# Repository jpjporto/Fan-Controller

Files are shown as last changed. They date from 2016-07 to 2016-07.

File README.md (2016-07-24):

# Fan-Controller
Fan controller system for watercooled computer. The board currently monitors the inlet/outlet temperature of each radiator in the system, and then sets the desired fan speed based on the difference between the average loop temperature and the external temperature.
The board also monitors the flow rate in the system, and can set the pump to match a desired flow rate.
The board is also capable of driving a RGB LED strip along with a single color LED strp (UV LEDs in my case).

Lastly, the board has WiFi capabilities through an ESP8266 board. Currently the code is able to interfarce with MSI Afterburner Remote Server and read the CPU & GPU temperatures.
I haven't developed this part much (mostly due to lack of time), but my idea is to have the board send out information such as fan speeds and have the user read out the information on a webserver or an app. This would also allow the user to change the LED colors and brightness.

The board is powered via a single molex connector (AMP MATE-N-LOK 1-480424-0). Obviously, the power used depends on how many fans/which fans are used and the LEDs used. The 12V trace powering the fans/LEDs is 75mils wide, so it is not recommended pulling more than 6Amps through the 12V for a 1oz copper board.
For reference, a Corsar SP120 High-performance PWM fan draws around 0.13 Amps at 100% duty cycle (and 0.2 Amps during power up). A 5050 LED strip with 18 SMDs/ft draws around 0.2 Amps per feet.

### Capabilities ###
* Control and monitor up to 7 PWM fans (can control more if using 4-pin fan cable splitters)
* Control and monitor 1 Pump
* Monitor up to 7 10k Ohms temperature sensors (6 inline sensors and 1 external sensor)
* Monitor 1 flow sensor (the code is desined to use a Koolance INS-FM17N flow meter, but can be easily modified to support different sensors)
* Brightness and Color control of an RGB LED strip and a single color LED strip.
* WiFi (needs to be developed though)

### Configuration ###
Sadly, this project is (currently) not simply "plug-and-play". The user needs to modify a few things to get the code working. 
Most importantly, one needs to modify the first few lines of the esp_main.ino code to add their SSID and MSI afterburner information.
The user also needs to modify the wc_board.ino code so it knows how many fans are being connected and how many radiators/temp sensors the system has.

### To-Do List ###
* Control/monitor throught wifi
* Warn the user if the pump has stopped or if the temperature gets really high. Since I don't have a buzzer, one idea was to have the LEDs flash.
* Add some nice light effects, like fade-in, or rainbow cycle.
* Fan calibration (i.e. find slowest operating speed)
* Detect number of fans and sensors connected, and automatically calibrate the system.
* Fan RPM control. The MAX31790 chips support controlling the fans by setting the desired RPM rate (as opposed to setting the desired duty cycle). I tried this before but for some reason it wasn't working.
* Figure out how to have Windows recognize the board so monitoring softwares (like HWMonitor, Corsair Link, or MSI Afterburner) could report fan speeds and loop temperatures.
* Improve this readme file.

If anyone is interested in helping out with the code, feel free to push commits.

### Repository structure ###

* ./esp_main

Includes the code for the ESP8266 board. For more information about the ESP8266 board and flashing it, please refer to https://github.com/esp8266/Arduino

* ./libraries

Includes the necessary libraries to run the Teensy code. The I2Cdev library included is probably out-of-date, but guaranteed to work with the code in this repo.

* ./PCB

Includes all the schematic files necessary to modify the pcb board along with gerber files for manufacturing. The pcb was generated using Altium Designer 16, however, feel free to email me asking for files for difference programs. I believe Altium allows me to generate source files for many different programs.

* ./wc_board

Includes the main code. I'm using a Teensy 3.2.

### Third-Party Software ###
I've used the MSI Afterburner GUI & Remote Server application for my code. Both are available on the [MSI Afterburner website](http://event.msi.com/vga/afterburner/overview.htm). This code is currently capable of interfacing with MSI Afterburner versions :
* MSI Afterburner GUI Version 4.1.1.7625
* MSI Afterburner Remote Server v1.2.0.0

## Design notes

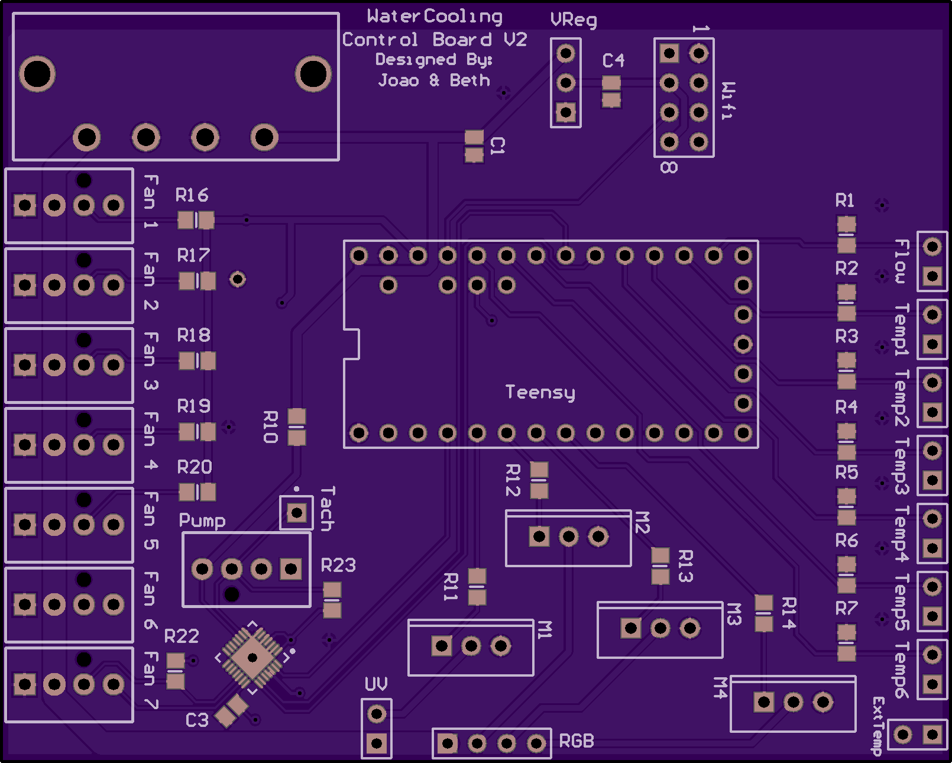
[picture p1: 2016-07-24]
PCB/pcb_top.png

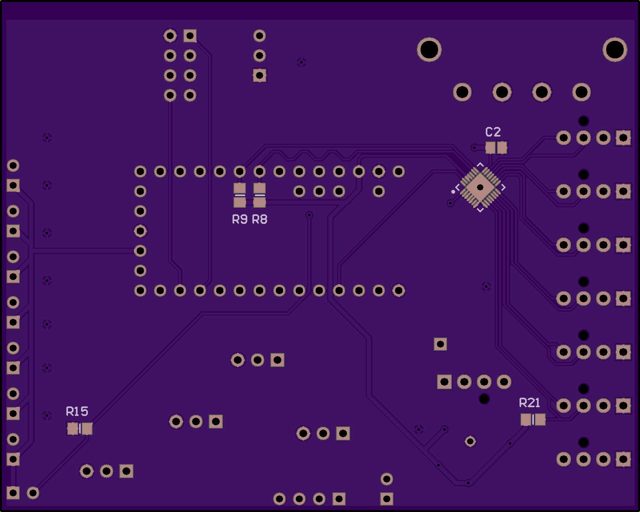
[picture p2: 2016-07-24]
PCB/pcb_bottom.png

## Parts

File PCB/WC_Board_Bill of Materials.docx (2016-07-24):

WaterCooling Board:

Description | Digikey P/N | Qnty | Board Reference
IC MOTOR CONTROLLER I2C 28TQFN MAX31790 | MAX31790ATI+-ND | 2
MOSFET N-CH 30V 62A TO-220AB | IRLB8721PBF-ND | 4 | M(1-4)
IC REG LDO 3.3V 0.8A TO220AB | 497-1491-5-ND | 1 | Vreg
RES SMD 10K OHM 1% 1/8W 0805 | 1276-5332-1-ND | 12 | R(1-7,10-14)
RES SMD 4.7K OHM 1% 1/8W 0805 | P4.70KCCT-ND | 2 | R8,R9
CAP 0.1uF 50V CERAMIC X7R 0805 | 399-1170-1-ND | 3 | C1,C2,C3
CAP 10uf 16V CERAMIC X5R 0805 | 399-8012-1-ND | 1 | C4
MOLEX POWER CONNECTOR | A122356-ND | 1
4PIN FAN HEADER | WM4330-ND | 8 | FAN (1-7), PUMP
TERM BLOCK 2POS SIDE ENT 2.54MM | A98333-ND | 1 | UV
TERM BLOCK 4POS SIDE ENT 2.54MM | A98335-ND | 1 | RGB
8 Position Header Connector 0.100" (2.54mm) Through Hole Tin | S7072-ND | 1 | Wifi
Headers
Teensy 3.2 | 1568-1231-ND | 1
ESP8266 | 1568-1235-ND | 1

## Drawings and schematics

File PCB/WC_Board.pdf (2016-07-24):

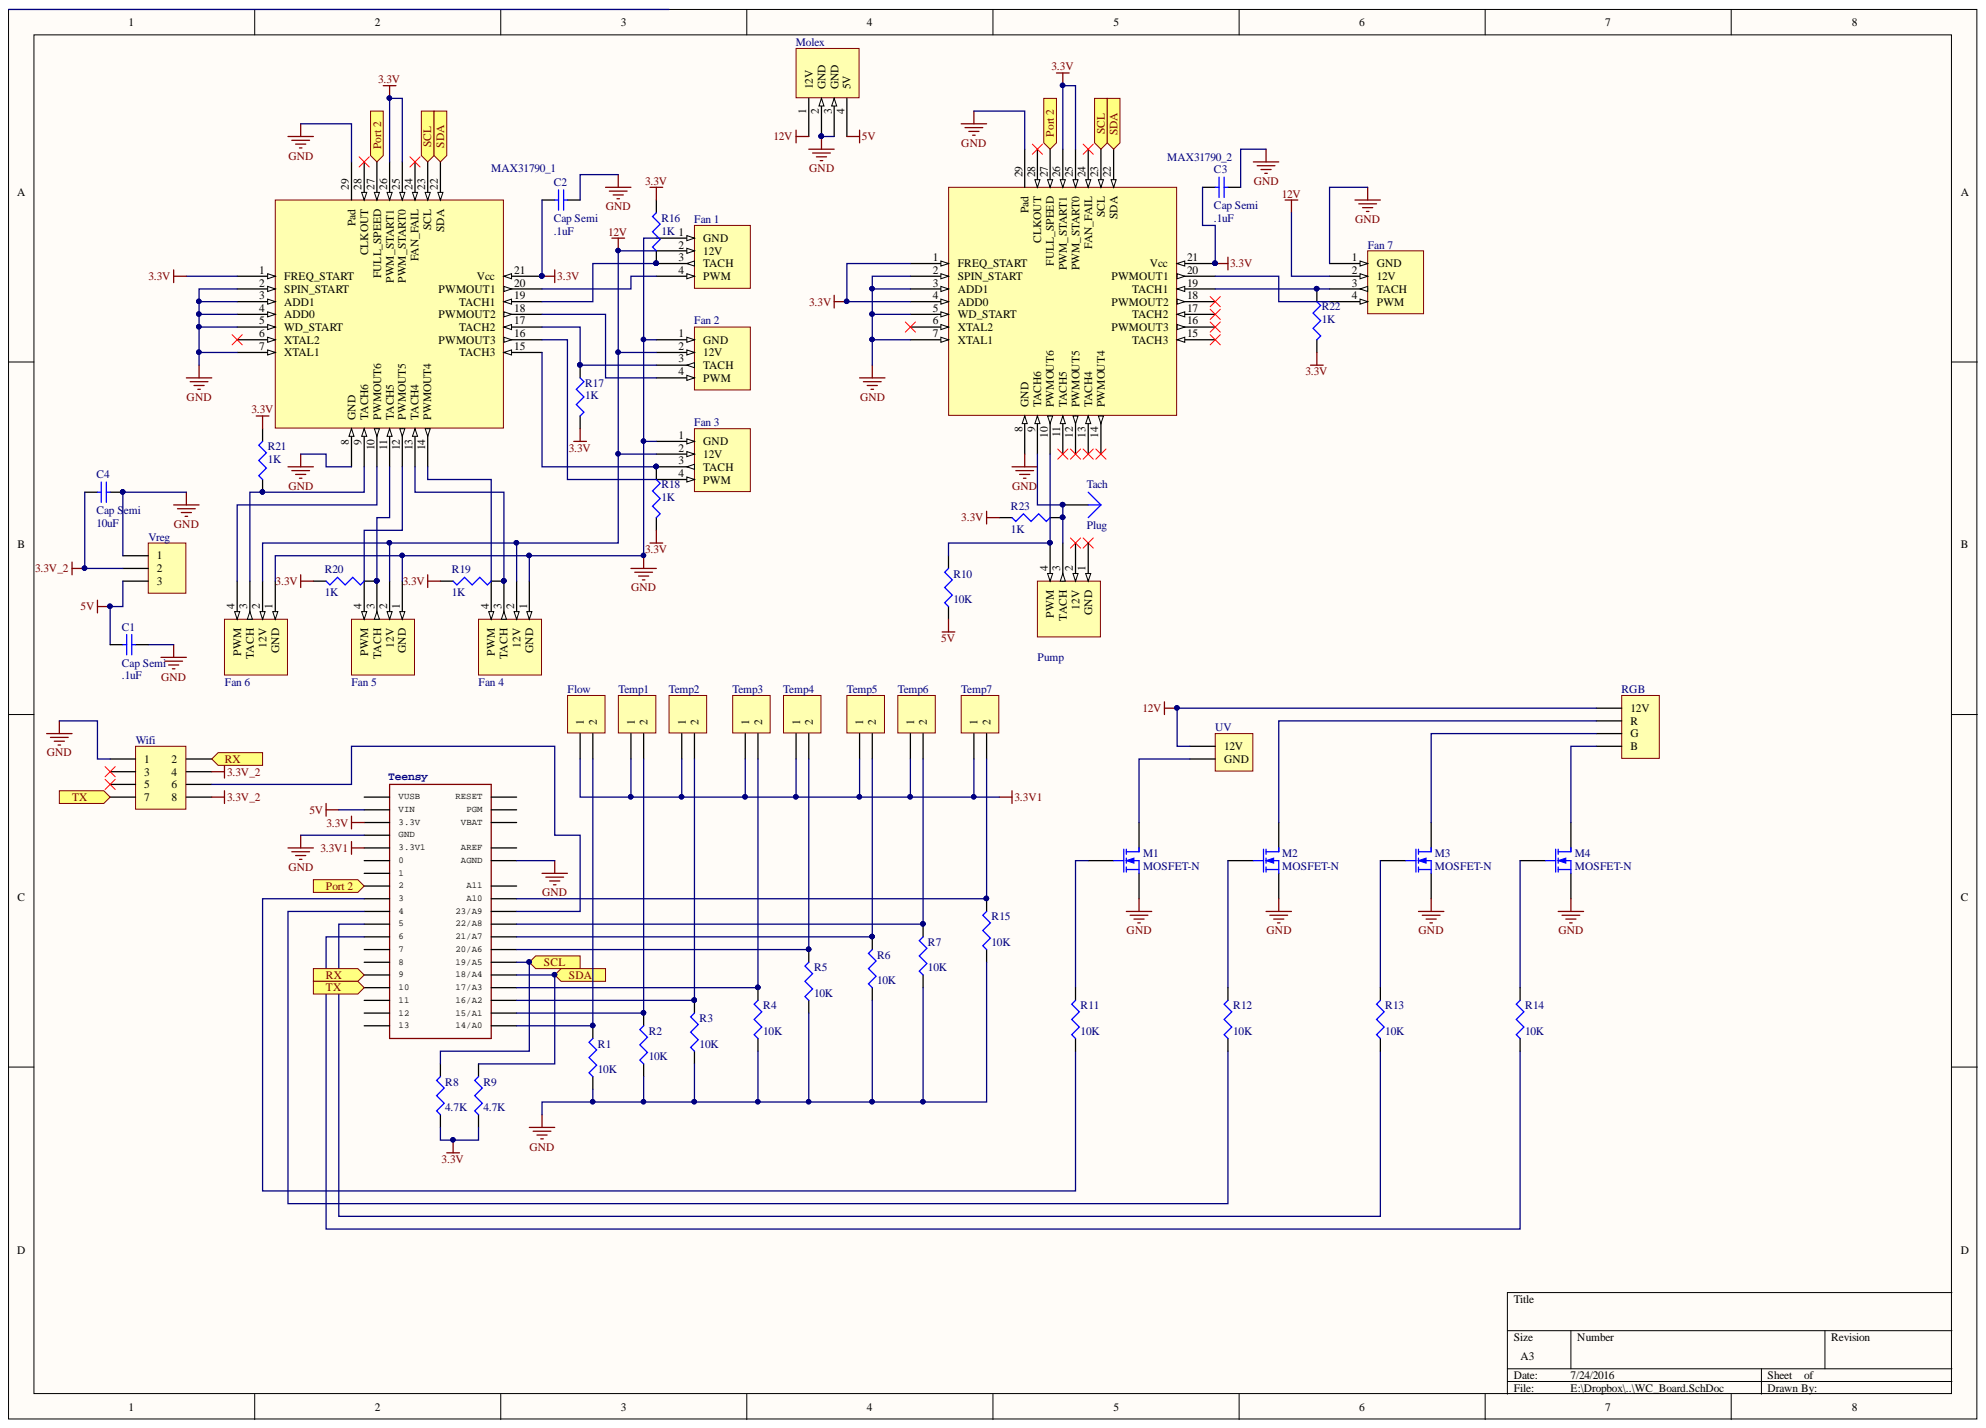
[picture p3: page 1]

SDA 22 SCL 23 FAN_FAIL 24 PWM_START0 25 PWM_START1 26 FULL_SPEED 27 CLKOUT 28 Pad 29

XTAL1 7 | 12V 2

TACH 3
PWM 4

Cap Semi 10uF | Vreg

GND 1 12V 2 TACH 3 PWM 4 Pump

GND 1 12V 2 TACH 3 PWM 4 Fan 6

GND 1 12V 2 TACH 3 PWM 4 Fan 5

GND 1 12V 2 TACH 3 PWM 4 Fan 4

4 23/A9
5 22/A8 | R15

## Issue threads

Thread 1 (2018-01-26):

Pull-Ups on PWM pins

dross92, 2018-01-26:
Hi,
I am designing a circuit using the MAX31790 and have referenced your design.  I noticed that you wire the fan's PWM pin straight into the MAX's PWMOUT, however the MAX datasheet specifies PWMOUT is an open-drain output so it must be pulled up to Vcc.  Basically, I was wondering if your circuit functioned properly without these pull-ups.
Please let me know.

Thanks,
Drew

jpjporto, 2018-01-26:
Hi,

The circuit assumes that the fan connected follows the [4-Wire PWM Fan Specs](http://www.formfactors.org/developer%5Cspecs%5C4_Wire_PWM_Spec.pdf), so each fan internally pulls the PWM signal to Vcc.

Best,
Joao

dross92, 2018-01-26:
OK, thank you!

Closed 2018-01-26.

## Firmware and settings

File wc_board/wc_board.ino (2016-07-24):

/*************************************************
 *	
 *	Watercooling Board Control Software
 *	For use with watercooling board available at https://github.com/jpjporto/Fan-Controller
 *
 *	Latest update on 07/24/2016 by Joao Paulo Porto <jpjporto(at)gmail.com>
 *
 *	Important Notice: This code has been stably running on my loop for at least a month (up to 14hours).
 *		However, I make no guarantees about it.
 *
 *	If you think this code is cool, feel free to use or modify it. However, it would be nice of you to
 *	let me know and give proper attribution back.
 *
 *	Changelog:
 *		v0.1.0 - First release.
 *
 *************************************************/


#include <i2c_t3.h>
#include "MAX31790.h"
#include "I2Cdev.h"
#include <PID_v1.h>

//Pin definitions
#define TEMP1 A1
#define TEMP2 A2
#define TEMP3 A3
#define TEMP4 A6
#define TEMP5 A7
#define TEMP6 A8
#define TEMP_EXT A10 //external temp
#define FLOW  14
#define FULL_SPEED  2
#define UV_PIN 3
#define G_PIN 4
#define R_PIN 5
#define B_PIN 6
#define ESP_RST 23

//System defs
#define NUM_RADS 2
#define NUM_FANS 5
#define NUM_TEMP 5 //rads*2 + 1

//MAX31790 fan_board(B0100000);
MAX31790 fan_board(0x40 >> 1);
MAX31790 fan_board2(0x46 >> 1);

char incomingByte = 0;

const int ANALOG_READ_RESOLUTION = 10; // Bits of resolution for the ADC.
const int ANALOG_READ_AVERAGING = 4;  // Number of samples to average with each ADC reading.

//Temp sensor values
uint16_t _nominalResistance = 10000;
uint16_t _seriesResistance = 10000;
uint16_t _betaCoefficient = 3950;
uint8_t _nominalTemperature = 25;

elapsedMillis flow_dt, flow_sample, temp_sample, fan_sample;
unsigned long timenow, lastPump, lastTemp;

uint32_t flow_read = 0;
uint8_t flow_count = 0;
double FlowMeas, prevFlowMeas, favg;
double FlowFreq;

double Setpoint = 1; //Desired flow = 1 gpm
double Output = 480; //Pump starting rate;

PID pumpPID(&FlowMeas, &Output, &Setpoint, 2, 6, 0.5, DIRECT);

//Sample Times
uint32_t Ts_pump = 500; // Flow sensor sample time, 0.5 seconds
uint32_t Ts_temp = 10;  // Get new temp data every 10msec
uint32_t Ts_fan  = 1000; // Check temperature readings and update fan speeds every 1 second

float rad_input[NUM_RADS], rad_output[NUM_RADS], ext_temp, rad_avg;
uint16_t fanspeed[NUM_FANS];
uint16_t pumpspeed;

bool temp_flag = 0;
uint8_t tempCount = 0;
uint32_t tempSum[NUM_TEMP];
float tempAvg[NUM_TEMP];

int MSI_cpu_temp, MSI_gpu_temp;
bool MSI_data = false;

// Fan curve settings
// please modify this to desired numbers.
uint8_t fan_dT[]  = {5,  10, 15, 20, 25, 30};
uint8_t fan_PWM[] = {40, 60, 70, 80, 90, 100};
float dT;
uint8_t steps = 6;
uint16_t fanPWMTarget;

//Struct for rgb strings
struct COLOR {
  uint8_t r;
  uint8_t g;
  uint8_t b;
};

COLOR default_color = {0, 0, 50};

void setup() {
  Wire.begin();
  Serial.begin(115200);
  Serial2.begin(115200);
  Serial2.setTimeout(100);

  pinMode(FLOW, INPUT);
  pinMode(TEMP1, INPUT);
  pinMode(TEMP2, INPUT);
  pinMode(TEMP3, INPUT);
  pinMode(TEMP4, INPUT);
  pinMode(TEMP5, INPUT);
  pinMode(TEMP6, INPUT);
  pinMode(TEMP_EXT, INPUT);

  pinMode(UV_PIN, OUTPUT);
  pinMode(R_PIN, OUTPUT);
  pinMode(G_PIN, OUTPUT);
  pinMode(B_PIN, OUTPUT);
  pinMode(FULL_SPEED, OUTPUT);
  //pinMode(ESP_RST, OUTPUT);

  analogReadResolution(ANALOG_READ_RESOLUTION);
  analogReadAveraging(ANALOG_READ_AVERAGING);

  digitalWrite(FULL_SPEED, HIGH);
  //digitalWrite(ESP_RST, LOW);

  setUV(200);
  setRGB(default_color);


  fan_board.initialize();
  fan_board2.initialize();

  pumpPID.SetOutputLimits(0, 511);
  pumpPID.SetSampleTime(Ts_pump);
  //pumpPID.SetMode(AUTOMATIC); //Uncomment this if you want the pump rate to match the desired Setpoint above

  flow_dt = 0;
  attachInterrupt(FLOW, flowISR, RISING);
}

void loop() {
  if (flow_sample > Ts_pump)
  {
    flow_sample = 0;
    //Serial.println(flow_count);
    FlowFreq = 1000.*flow_count / flow_read;
    flow_read = 0;
    flow_count = 0;
    FlowMeas = FlowFreq * 0.307 * 0.264172; //flow in GPM, values from INS-FM17N datasheet
    //favg = 0.5 * FlowMeas + 0.5 * prevFlowMeas;
    //prevFlowMeas = FlowMeas;
    pumpPID.Compute();
    setPumpPWM(Output);
    //Serial.printf("flow: %f gpm\n", FlowMeas);
  }

  /* This may look confusing, but the idea is to get an average of the temperature readings
     right before we update the fan speeds.
  */
  if ((temp_flag == 0) && (fan_sample > 750) && (temp_sample > Ts_temp) )
  {
    readTemps();
    temp_sample = 0;
  }

  if (fan_sample > Ts_fan)
  {
    dT = rad_avg - ext_temp;
    float interp_result = interpolate(dT, fan_dT, fan_PWM, steps);
    fanPWMTarget = interp_result * 5.11; //equivalent to map(interp_result,0,100,0,511)
    setAllPWM(fanPWMTarget);
    fan_sample = 0;
    temp_flag = 0;
    getAllRPM();
    //Serial.printf("dT: %f; rad_avg: %f, ext: %f, PWM: %f\n", dT, rad_avg, ext_temp, interp_result);
    //Serial.printf("Rad in: %f, Rad out: %f\n", rad_input[0], rad_output[0]);
    //Serial.println(pumpspeed);
    //Serial.println(fanspeed[0]);
  }

  if (Serial2.available()) // Check if the ESP8266 board sent new information
  {
    incomingByte = Serial2.read();
    if (incomingByte == 'C')
    {
      MSI_cpu_temp = Serial2.parseInt();
      MSI_gpu_temp = Serial2.parseInt();
      MSI_data = true;
    }

  }


}

uint32_t flow_temp;
void flowISR()
{
  flow_temp = flow_dt;
  if (flow_temp > 5) // added a small window to reduce tachometer bounce
  {
    flow_read += flow_dt;
    flow_dt = 0;
    flow_count++;
  }
}

float getTemp(float pin_value)
{
  float pin_volt = _seriesResistance * ((pow(2.0, ANALOG_READ_RESOLUTION) - 1) / pin_value - 1);
  float steinhart = (log(pin_volt / _nominalResistance)) / _betaCoefficient;
  steinhart += 1.0 / (_nominalTemperature + 273.15);
  steinhart = 1.0 / steinhart; // invert
  steinhart -= 273.15; // convert to celsius
  return steinhart;
}

/* Read temperature from sensors. My system only uses 5 sensors. */
void readTemps()
{
  tempSum[0] += analogRead(TEMP1);
  tempSum[1] += analogRead(TEMP2);
  tempSum[2] += analogRead(TEMP3);
  tempSum[3] += analogRead(TEMP4);
  tempSum[4] += analogRead(TEMP_EXT);
  //tempSum[5] += analogRead(TEMP6);
  //tempSum[6] += analogRead(TEMP7);
  tempCount++;
  if (tempCount == 10)
  {
    for (int j = 0; j < NUM_TEMP; j++)
    {
      tempAvg[j] = tempSum[j] / 10.;
      tempSum[j] = 0;
    }
    for (int i = 0; i < NUM_RADS; i++)
    {
      rad_input[i] = getTemp(tempAvg[2 * i]);
      rad_output[i] = getTemp(tempAvg[2 * i + 1]);
    }
    ext_temp = getTemp(tempAvg[4]); //2*NUM_RADS+1
    rad_avg = (rad_input[0] + rad_input[1] + rad_output[0] + rad_output[1]) / 4;
    tempCount = 0;
    temp_flag = 1;
  }
}

/* Set the PWM for all fans */
void setAllPWM(uint16_t pwm)
{
  for (int i = 1; i <= 6; i++)
  {
    fan_board.setPWM(pwm, i);
  }

  //#if NUM_FANS == 7
  fan_board2.setPWM(pwm, 1);
  //#endif
}

void setPumpPWM(uint16_t pwm)
{
  fan_board2.setPWM(pwm, 6);
}

void getAllRPM()
{
  for (int i = 0; i < 6; i++)
  {
    fanspeed[i] = fan_board.getRPM(i + 1);
  }
  //#if NUM_FANS == 7
  fan_board2.getRPM(1);
  //#endif

  pumpspeed = fan_board2.getRPM(6);
}

void setRGB(struct COLOR CC) {
  analogWrite(R_PIN, CC.r);
  analogWrite(G_PIN, CC.g);
  analogWrite(B_PIN, CC.b);
}
void setUV(uint8_t bright) {
  analogWrite(UV_PIN, bright);
}

float interpolate(float dT, uint8_t Temps[], uint8_t PWMs[], uint8_t N) {
  int i = 0;
  if (dT < Temps[0]) {
    return PWMs[0];
  } else if (dT > Temps[N - 1]) {
    return PWMs[N - 1];
  } else {
    while (dT > Temps[i]) {
      i++;
    }
    float slope = ( PWMs[i] - PWMs[i - 1]) / (float)(Temps[i] - Temps[i - 1]);
    return (slope * (dT - Temps[i - 1]) + PWMs[i - 1]);
  }
}

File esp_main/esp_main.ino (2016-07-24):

/**
   esp_main.ino

    Created on: 04.27.2016

*/

#include <Arduino.h>

#include <ESP8266WiFi.h>
#include <ESP8266WiFiMulti.h>
#include <ESP8266HTTPClient.h>

const char* host = "192.168.*.*"; // Add IP address of main desktop
const char* SSID = "My SSID"; // Add your SSID
const char* wifi_password = "My Password"; // Add your wifi password
const char* msi_auth_key = "17cc95b4017d496f82"; // Add the MSI afterburner remote server security key

HTTPClient http;
ESP8266WiFiMulti WiFiMulti;

unsigned long timenow, lasttime;

long cpu_temp = 0;
long gpu_temp = 0;
int Ts = 5000; //time for reading samples from MSI, 5seconds.
uint8_t flag = 0;

void getTemps(String);

int incomingByte = 0;

void setup() {

  Serial.begin(115200);

  for (uint8_t t = 4; t > 0; t--) {
    //Serial.printf("[SETUP] WAIT %d...\n", t);
    //Serial.flush();
    delay(1000);
  }

  WiFiMulti.addAP("Minas Anor", "SecretPassword");
  http.setReuse(true);
  lasttime = 0;
}

void loop() {
  // wait for WiFi connection
  timenow = millis();
  if ((timenow - lasttime) > Ts) {
    if ((WiFiMulti.run() == WL_CONNECTED)) {
      lasttime = timenow;
      //Serial.print("[HTTP] begin...\n");
      // configure traged server and url
      http.begin(host, 82, "/mahm");
      //http.setAuthorization("TVNJQWZ0ZXJidXJuZXI6MTdjYzk1YjQwMTdkNDk2Zjgy");
	  http.setAuthorization("MSIAfterburner", msi_auth_key);

      //Serial.print("[HTTP] GET...\n");
      // start connection and send HTTP header
      int httpCode = http.GET();

      // httpCode will be negative on error
      if (httpCode > 0) {
        // HTTP header has been send and Server response header has been handled
        //Serial.printf("[HTTP] GET... code: %d\n", httpCode);

        // file found at server
        if (httpCode == HTTP_CODE_OK) {
          String payload = http.getString();
          getTemps(payload);
          flag = 1;
        } else {
          flag = 0;
        }
      } else {
        flag = 0;
      }

      http.end();
    } else {
      flag = 0;
    }
  }

  if (flag == 1) { //send data to teensy
    Serial.printf("C:%d;G:%d\n", cpu_temp, gpu_temp);
    flag = 0;
  }
}

void getTemps(String msi_data)
{
  int index = 0;
  int index_data = 0;
  //Serial.println(msi_data.substring(0, msi_data.indexOf("encoding")));

  //Might change later so it averages cpu data;
  index = msi_data.indexOf("CPU temperature");
  if (index > 0)
  {
    //Serial.println("Hello");
    index_data = msi_data.indexOf("<data>", index);
    if (index_data > 0)
    {
      String cpu_data = msi_data.substring(index_data + 6, index_data + 10); //size of "<data>" = 6; number should be less than 4 digits
      cpu_temp = cpu_data.toInt();
    }
  }

  index = msi_data.indexOf("GPU temperature");
  if (index > 0)
  {
    index_data = msi_data.indexOf("<data>", index);
    if (index_data > 0)
    {
      String gpu_data = msi_data.substring(index_data + 6, index_data + 10); //size of "<data>" = 6; number should be less than 4 digits
      gpu_temp = gpu_data.toInt();
    }
  }
}

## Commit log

2016-04-04 added teensy i2c library
2016-04-04 added I2CDev library
2016-04-26 Simple teensy sketch to test MAX31790 board
2016-07-24 Added board render and schematic pdf
    [WC_Board_Backup.PcbDoc, WC_Board_Backup2.PcbDoc, WC_Board_Backup3.PcbDoc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]
